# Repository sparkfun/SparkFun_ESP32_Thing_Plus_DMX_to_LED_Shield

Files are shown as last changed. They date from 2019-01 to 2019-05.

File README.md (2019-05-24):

SparkFun ESP32 Thing Plus DMX to LED Shield
========================================

SparkFun ESP32 DMX to LED Shield

[*SparkFun ESP32 DMX to LED Shield(DEV-15110)*](https://www.sparkfun.com/products/15110)

The SparkFun ESP32 DMX to LED Shield is capable of DMX output, input, as well as Artnet input. The shield is electrically isolated to keep with DMX spec. This library has been written to control DMX output and input.

Repository Contents
-------------------

* **/Hardware** - Eagle design files (.brd, .sch)
* **/Production** - Production panel files (.brd)

Documentation
--------------
* **[Hookup Guide](https://learn.sparkfun.com/tutorials/sparkfun-esp32-dmx-to-led-shield)** - Basic hookup guide for the [SparkFun ESP32 DMX to LED Shield](https://www.sparkfun.com/products/15110).

License Information
-------------------

This product is _**open source**_! 

Please review the LICENSE.md file for license information.

If you have any questions or concerns on licensing, please visit the [SparkFun Forum](https://forum.sparkfun.com/index.php) and post a topic.

Distributed as-is; no warranty is given.

- Your friends at SparkFun.

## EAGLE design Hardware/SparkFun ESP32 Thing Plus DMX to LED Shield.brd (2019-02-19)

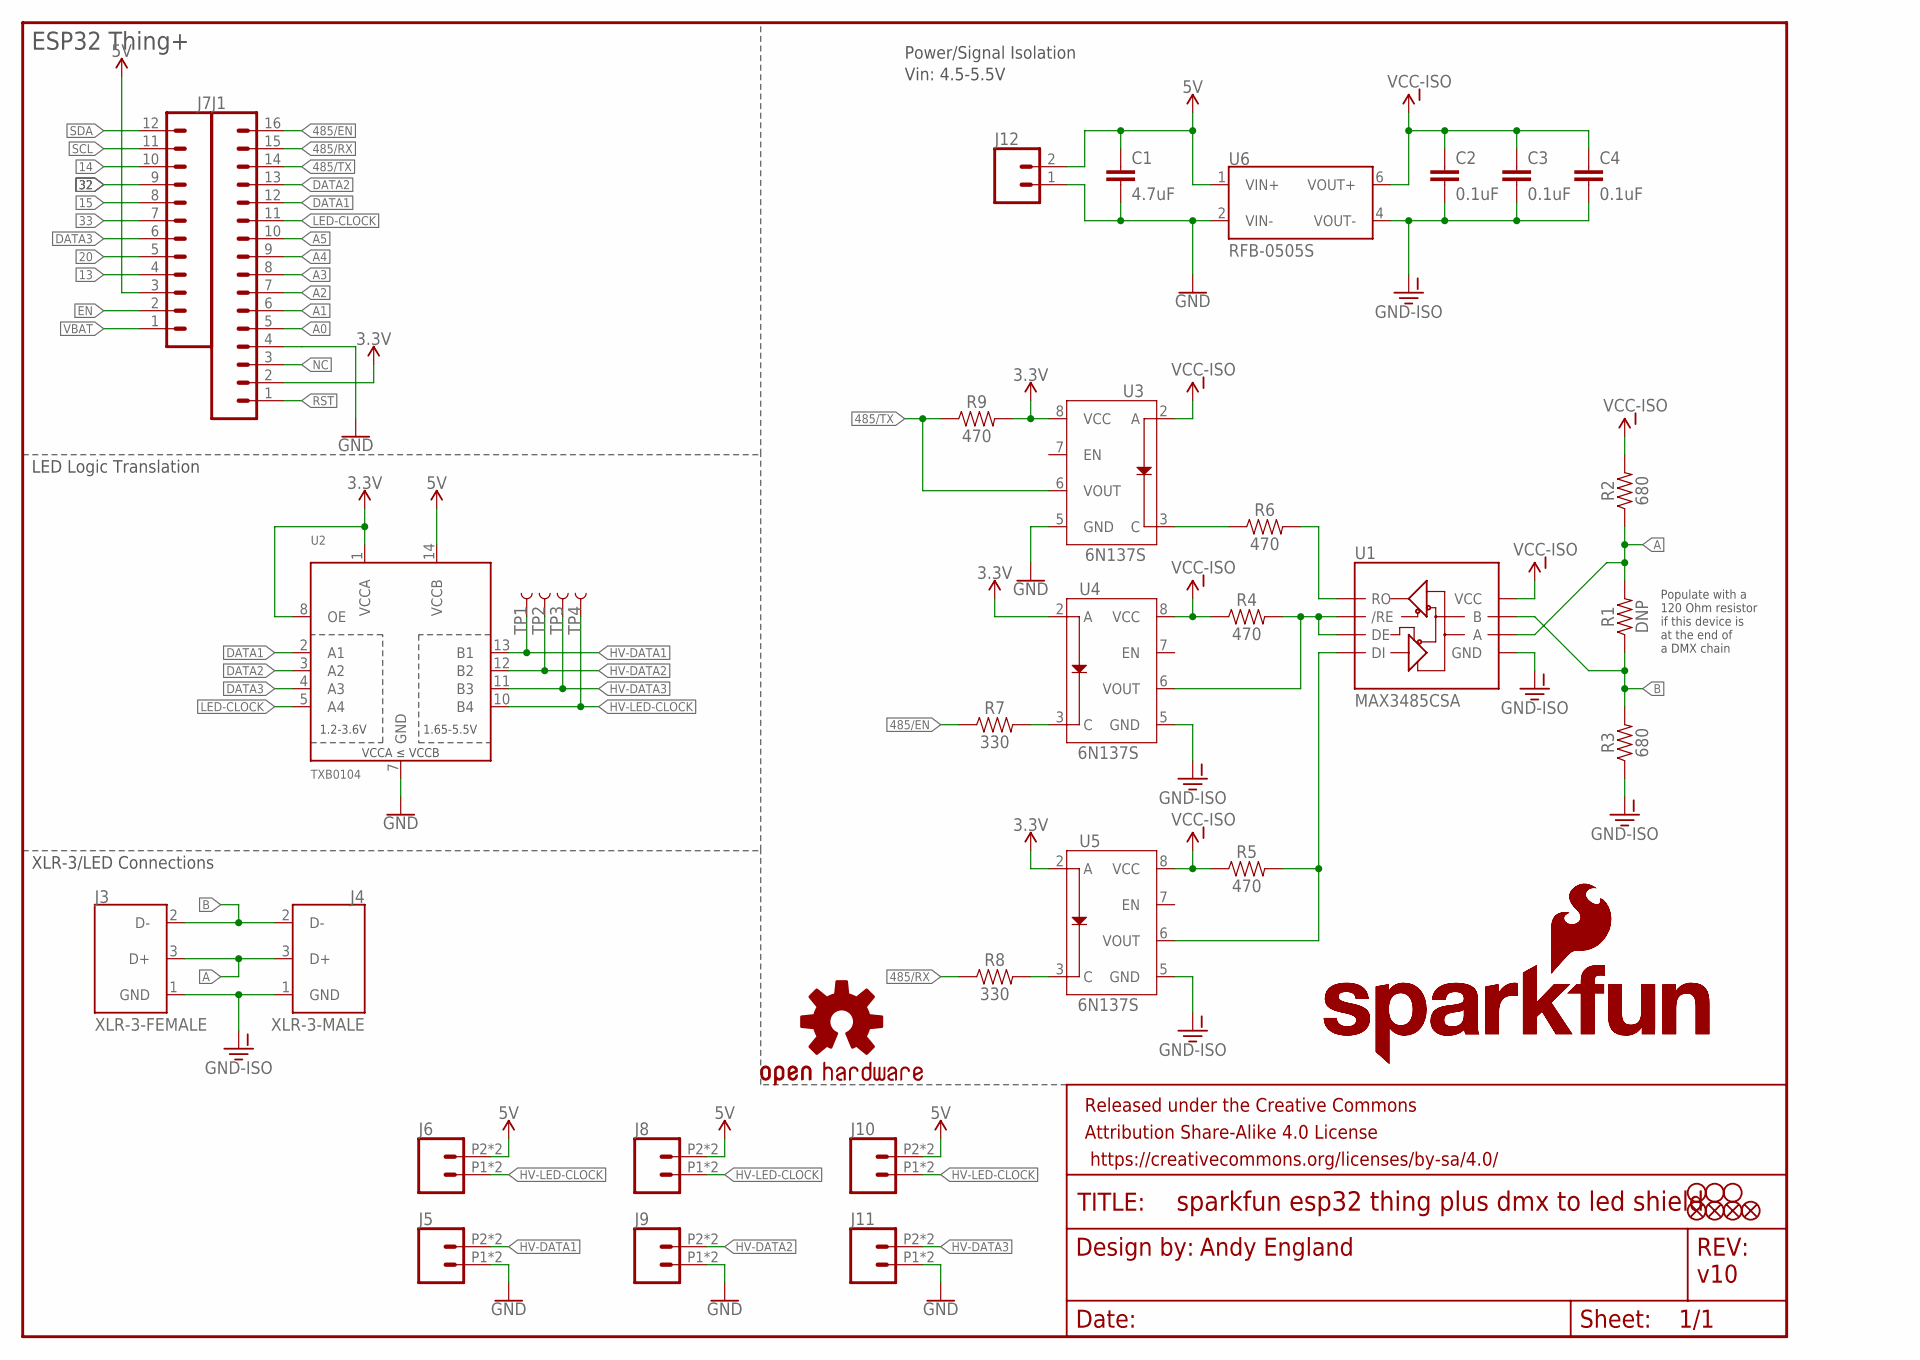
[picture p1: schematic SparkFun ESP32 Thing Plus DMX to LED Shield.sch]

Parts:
C1: 4.7uF; 0603
C2, C3, C4: 0.1uF; 0603
FD1, FD2, FD3, FD4: FIDUCIALUFIDUCIAL; FIDUCIAL-MICRO
FRAME1: FRAME-LETTER; CREATIVE_COMMONS
H1, H2, H3: STAND-OFFTIGHT; STAND-OFF-TIGHT
J1: CONN_16LOCK_NO_SILK; 1X16_LOCK_NO_SILK
J3: XLR-3-FEMALE; XLR-3_FEMALE
J4: XLR-3-MALE; XLR-3_MALE
J5, J6, J8, J9, J10, J11: CONN_02SMALL_POKEHOME; 1X02_POKEHOME
J7: CONN_12LOCK_NO_SILK; 1X12_LOCK_NO_SILK
J12: CONN_023.5MM; SCREWTERMINAL-3.5MM-2
LOGO1, LOGO2: SFE_LOGO_NAME_FLAME.2_INCH; SFE_LOGO_NAME_FLAME_.2
LOGO3: OSHW-LOGOS; OSHW-LOGO-S
R1: DNP; AXIAL-0.3EZ
R2, R3: 680; 0603
R4, R5, R6, R9: 470; 0603
R7, R8: 330; 0603
TP1, TP2, TP3, TP4: TEST-POINT3; PAD.03X.03
U1: MAX3485CSA; SO08
U2: TXB0104; TSSOP14
U3, U4, U5: 6N137S; 8-SMD
U6: RFB-0505S

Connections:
3.3V: J1.2, R9.2, U2.1 (VCCA), U2.8 (OE), U3.8 (VCC), U4.2 (A), U5.2 (A)
5V: C1.1, J6.P2 (2), J6.P4 (2), J7.3, J8.P2 (2), J8.P4 (2), J10.P2 (2), J10.P4 (2), J12.2, U2.14 (VCCB), U6.1 (VIN+)
13: J7.4
14: J7.10
15: J7.8
20: J7.5
32: J7.9
33: J7.7
485/EN: J1.16, R7.1
485/RX: J1.15, R8.1
485/TX: J1.14, R9.1, U3.6 (VOUT)
A: J3.3 (D+), J4.3 (D+), R1.P$2 (2), R2.1, U1.6 (A)
A0: J1.5
A1: J1.6
A2: J1.7
A3: J1.8
A4: J1.9
A5: J1.10
B: J3.2 (D-), J4.2 (D-), R1.P$1 (1), R3.2, U1.7 (B)
DATA1: J1.12, U2.2 (A1)
DATA2: J1.13, U2.3 (A2)
DATA3: J7.6, U2.4 (A3)
EN: J7.2
GND: C1.2, J1.4, J5.P1 (1), J5.P3 (1), J9.P1 (1), J9.P3 (1), J11.P1 (1), J11.P3 (1), J12.1, U2.7 (GND), U3.5 (GND), U6.2 (VIN-)
GND-ISO: C2.2, C3.2, C4.2, J3.1 (GND), J4.1 (GND), R3.1, U1.5 (GND), U4.5 (GND), U5.5 (GND), U6.4 (VOUT-)
HV-DATA1: J5.P2 (2), J5.P4 (2), TP1.P$1, U2.13 (B1)
HV-DATA2: J9.P2 (2), J9.P4 (2), TP2.P$1, U2.12 (B2)
HV-DATA3: J11.P2 (2), J11.P4 (2), TP3.P$1, U2.11 (B3)
HV-LED-CLOCK: J6.P1 (1), J6.P3 (1), J8.P1 (1), J8.P3 (1), J10.P1 (1), J10.P3 (1), TP4.P$1, U2.10 (B4)
LED-CLOCK: J1.11, U2.5 (A4)
unnamed: R8.2, U5.3 (C)
unnamed: R7.2, U4.3 (C)
unnamed: R4.2, U1.2 (/RE), U1.3 (DE), U4.6 (VOUT)
unnamed: R5.2, U1.4 (DI), U5.6 (VOUT)
unnamed: R6.1, U3.3 (C)
unnamed: R6.2, U1.1 (RO)
NC: J1.3
RST: J1.1
SCL: J7.11
SDA: J7.12
VBAT: J7.1
VCC-ISO: C2.1, C3.1, C4.1, R2.2, R4.1, R5.1, U1.8 (VCC), U3.2 (A), U4.8 (VCC), U5.8 (VCC), U6.6 (VOUT+)

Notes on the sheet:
ESP32 Thing+
Andy England
v10
LED Logic Translation
Power/Signal Isolation
XLR-3/LED Connections
Populate with a 120 Ohm resistor if this device is at the end of a DMX chain
Vin: 4.5-5.5V

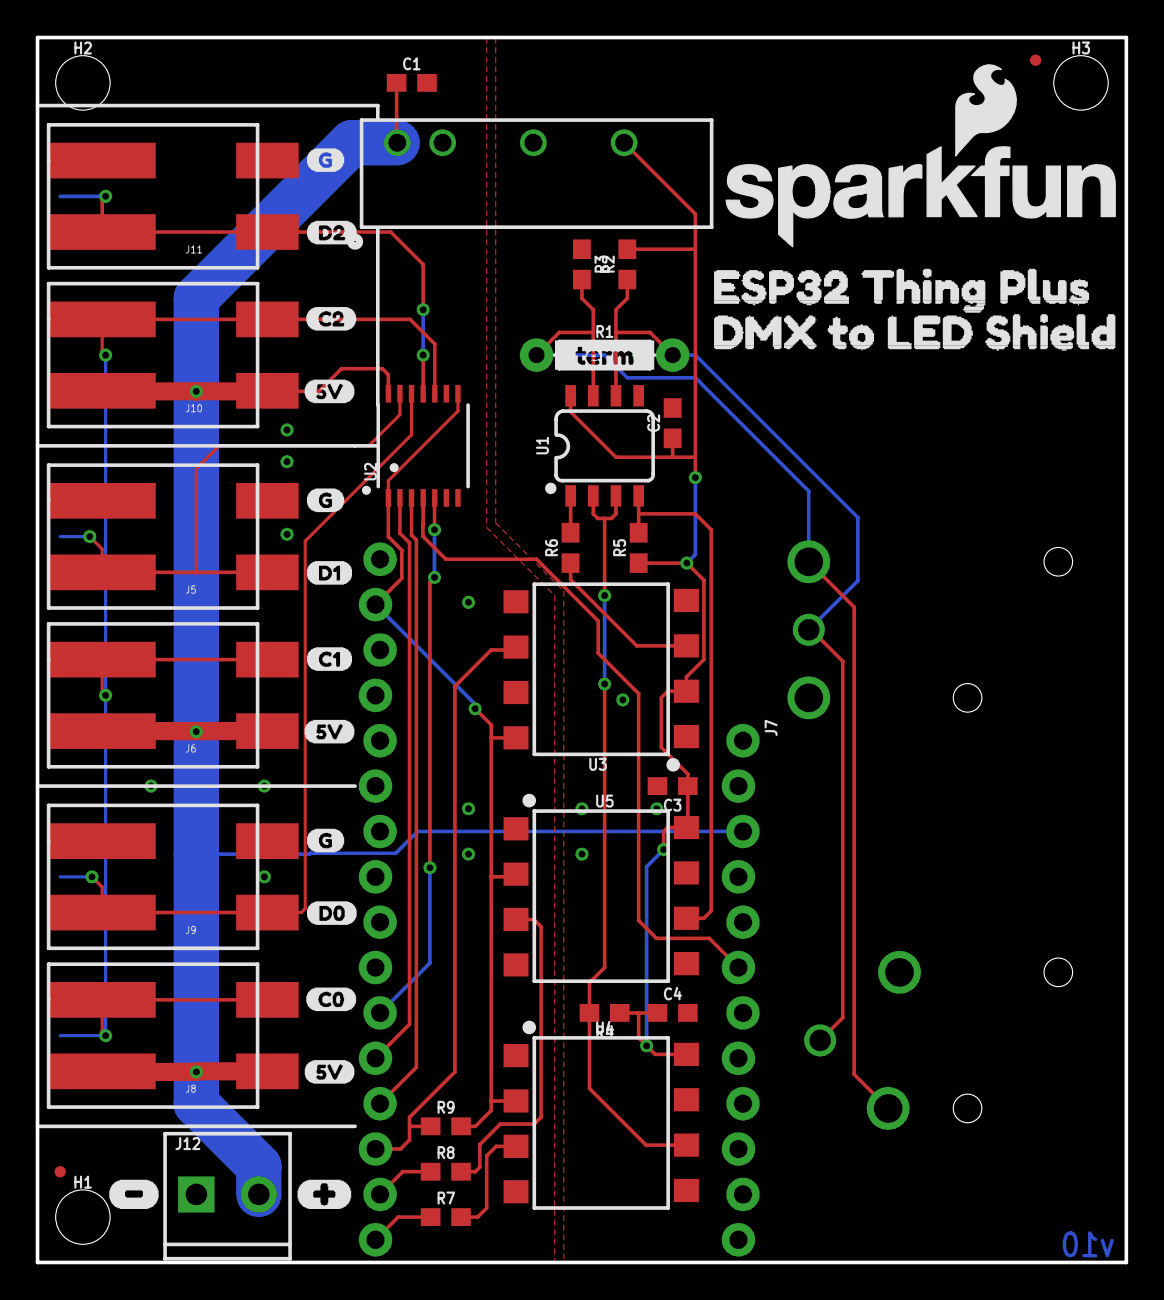
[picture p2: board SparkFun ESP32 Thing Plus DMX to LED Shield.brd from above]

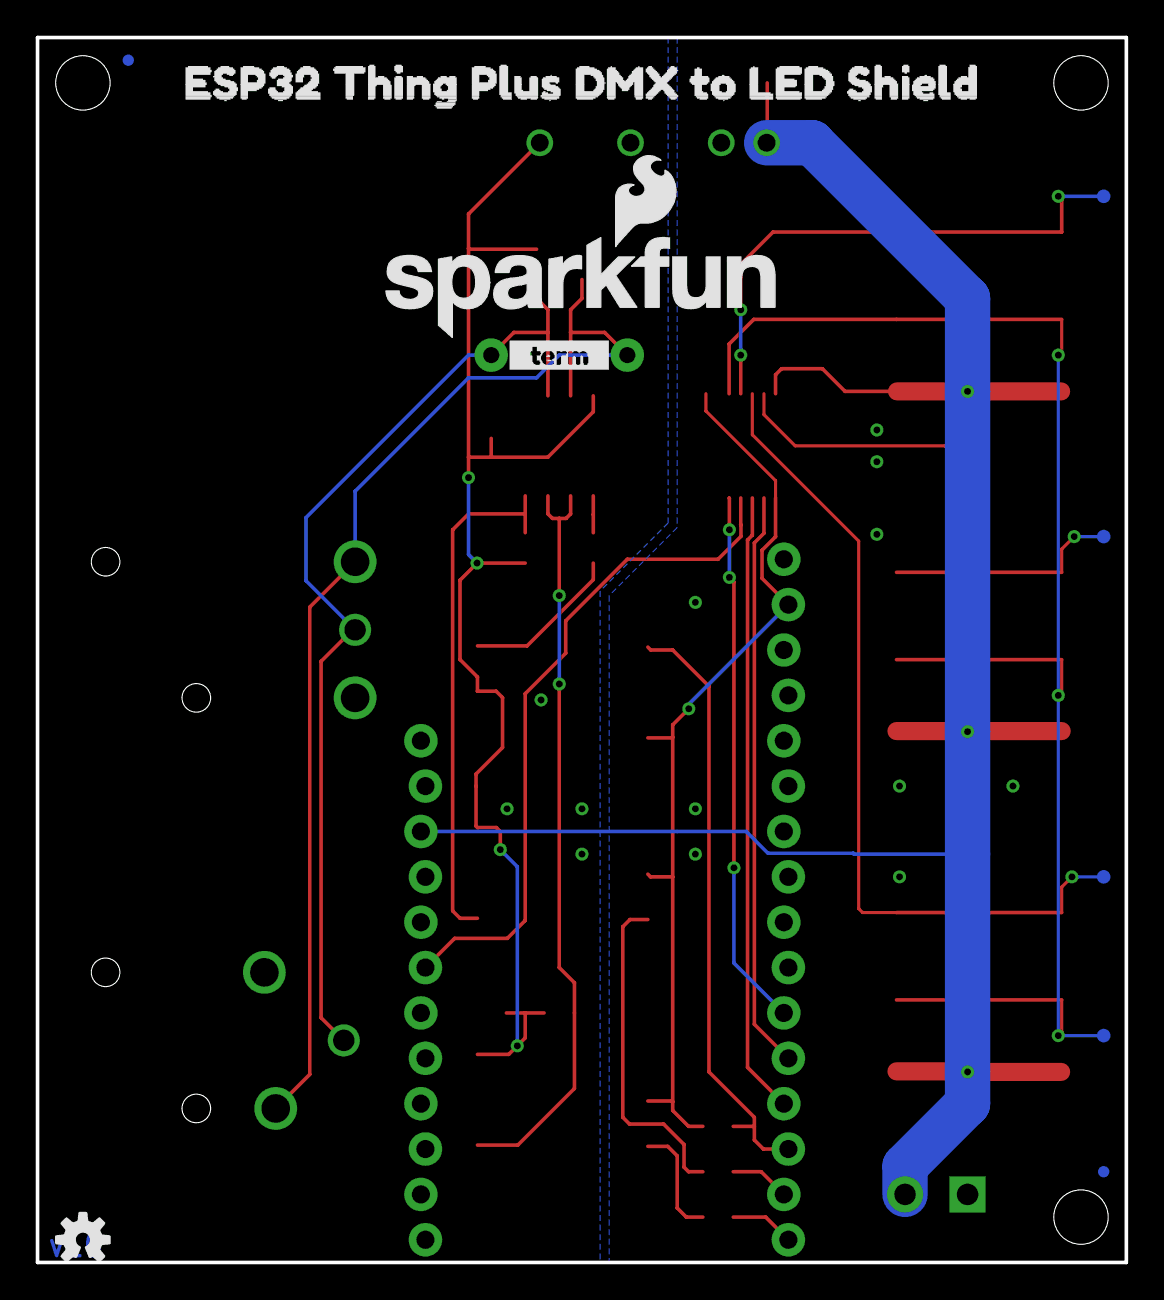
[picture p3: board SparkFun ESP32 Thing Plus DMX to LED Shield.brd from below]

Board: 2 copper layers, 61.0 x 68.6 mm, 65 parts (11 on the bottom side), 24 nets.

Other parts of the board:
U$1, U$2: __TERM__0
U$11, U$13: ESP32_THING_PLUS6
U$12, U$14: DMX_TO_LED_SHIELD7
U$15, U$17, U$21: 5V7
U$16: #0
U$18: C01
U$19: D00
U$20, U$24, U$28: G8
U$22: C12
U$23: D16
U$25: #1
U$26: C24
U$27: D23

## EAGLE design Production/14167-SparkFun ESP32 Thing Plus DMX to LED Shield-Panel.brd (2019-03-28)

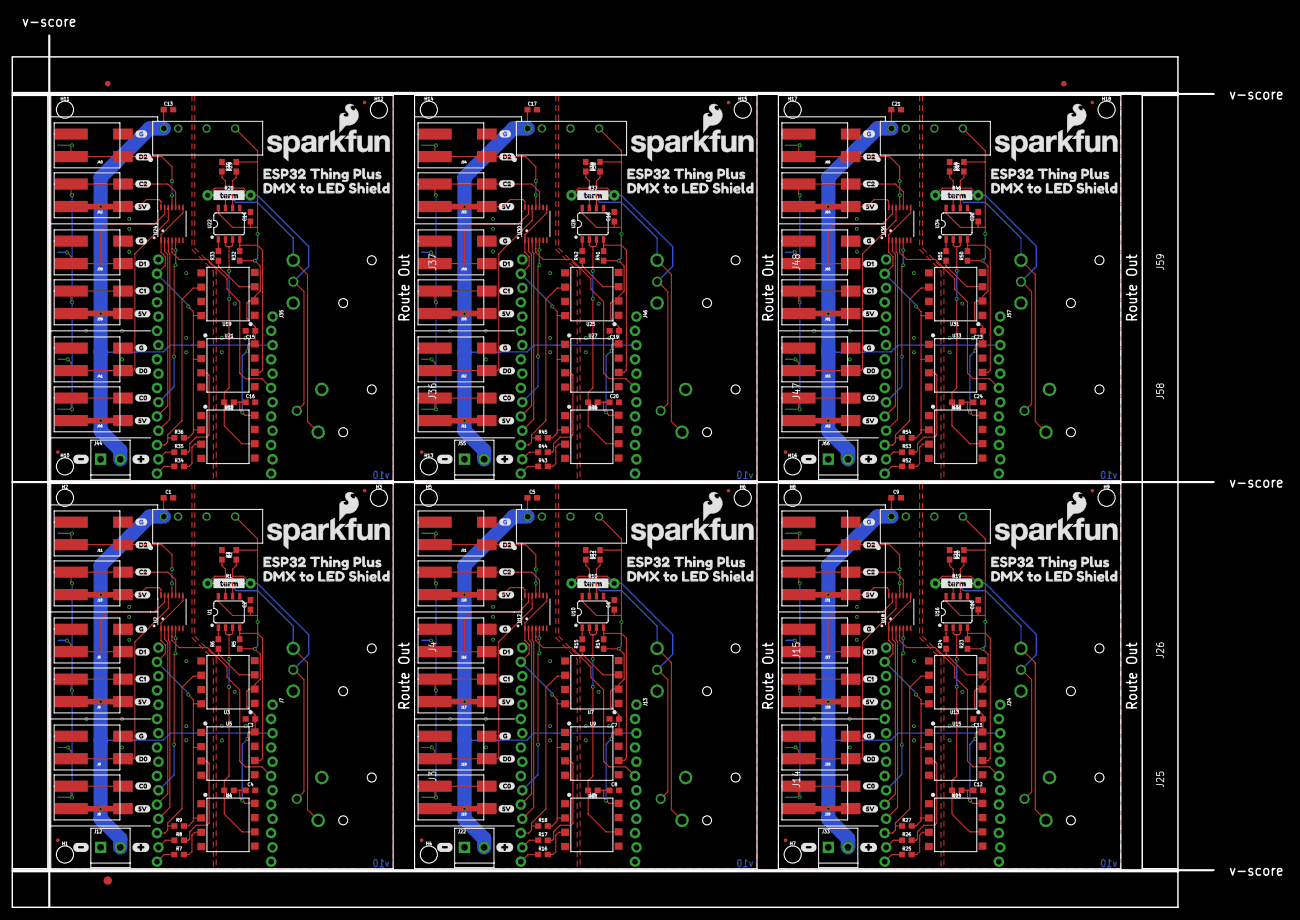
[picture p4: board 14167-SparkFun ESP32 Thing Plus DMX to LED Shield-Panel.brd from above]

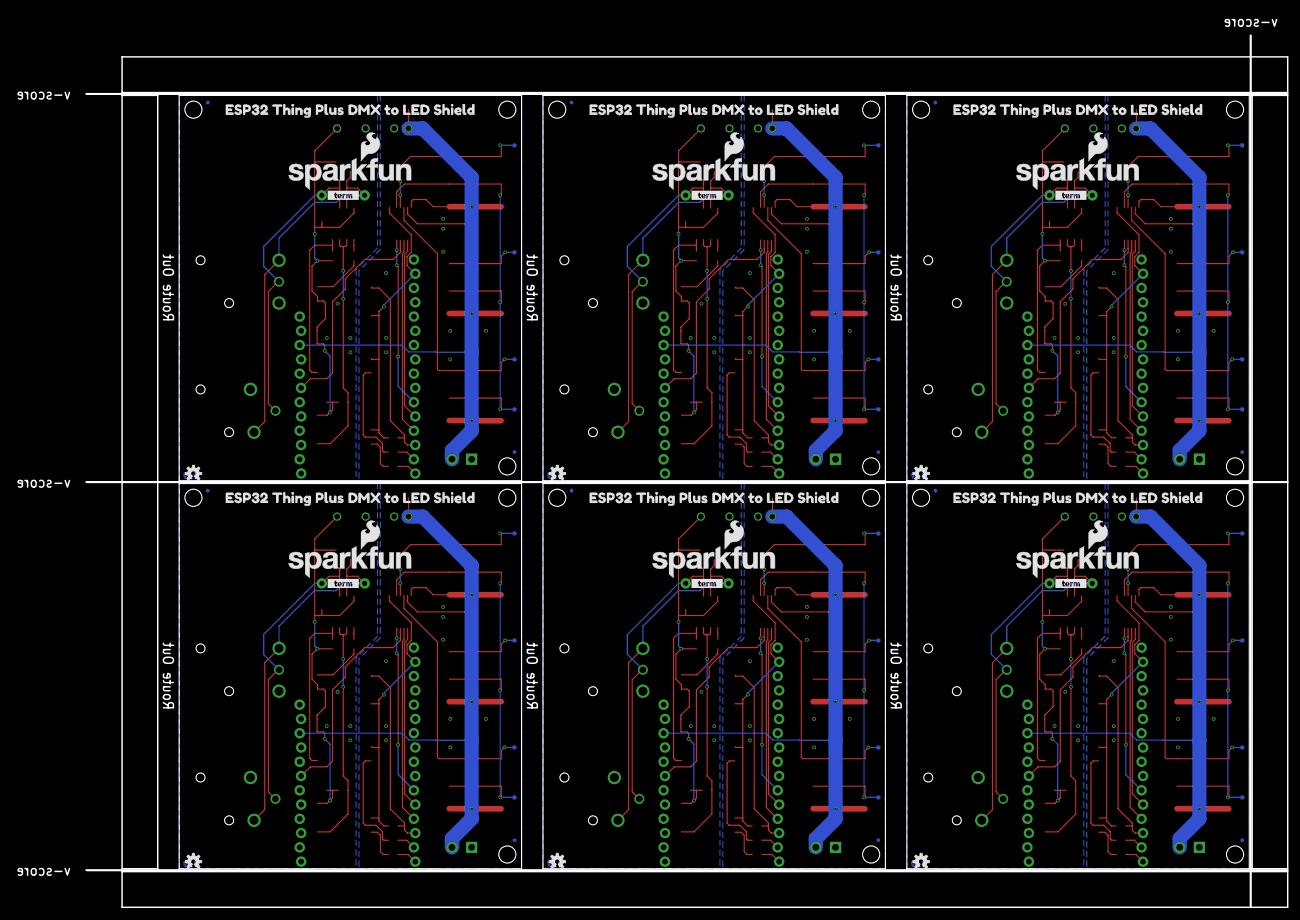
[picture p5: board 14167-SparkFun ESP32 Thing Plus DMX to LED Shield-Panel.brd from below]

Board: 2 copper layers, 213.8 x 155.2 mm, 387 parts (66 on the bottom side), 144 nets.

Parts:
C1, C5, C9, C13, C17, C21: 4.7uF; 0603
C2, C3, C4, C6, C7, C8, C10, C11, C12, C14, C15, C16, C18, C19, C20, C22, C23, C24: 0.1uF; 0603
E$1, E$2: FIDUCIAL-1X2
E$3: FIDUCIAL-1.5X3
FD1, FD2, FD3, FD4, FD5, FD6, FD7, FD8, FD9, FD10, FD11, FD12, FD13, FD14, FD15, FD16, FD17, FD18, FD19, FD20, FD21, FD22, FD23, FD24: FIDUCIALUFIDUCIAL; FIDUCIAL-MICRO
H1, H2, H3, H4, H5, H6, H7, H8, H9, H10, H11, H12, H13, H14, H15, H16, H17, H18: STAND-OFFTIGHT; STAND-OFF-TIGHT
J1, J2, J23, J34, J45, J56: 1X16_LOCK_NO_SILK
J3, J14, J25, J36, J47, J58: XLR-3-FEMALE; XLR-3_FEMALE
J4, J15, J26, J37, J48, J59: XLR-3-MALE; XLR-3_MALE
J5, J6, J8, J9, J10, J11, J16, J17, J18, J19, J20, J21, J27, J28, J29, J30, J31, J32, J38, J39, J40, J41, J42, J43, J49, J50, J51, J52, J53, J54, J60, J61, J62, J63, J64, J65: 1X02_POKEHOME
J7, J13, J24, J35, J46, J57: 1X12_LOCK_NO_SILK
J12, J22, J33, J44, J55, J66: SCREWTERMINAL-3.5MM-2
LOGO1, LOGO2, LOGO4, LOGO5, LOGO7, LOGO8, LOGO10, LOGO11, LOGO13, LOGO14, LOGO16, LOGO17: SFE_LOGO_NAME_FLAME.2_INCH; SFE_LOGO_NAME_FLAME_.2
LOGO3, LOGO6, LOGO9, LOGO12, LOGO15, LOGO18: OSHW-LOGOS; OSHW-LOGO-S
R1, R10, R19, R28, R37, R46: DNP; AXIAL-0.3EZ
R2, R3, R11, R12, R20, R21, R29, R30, R38, R39, R47, R48: 680; 0603
R4, R5, R6, R9, R13, R14, R15, R18, R22, R23, R24, R27, R31, R32, R33, R36, R40, R41, R42, R45, R49, R50, R51, R54: 470; 0603
R7, R8, R16, R17, R25, R26, R34, R35, R43, R44, R52, R53: 330; 0603
TP1, TP2, TP3, TP4, TP5, TP6, TP7, TP8, TP9, TP10, TP11, TP12, TP13, TP14, TP15, TP16, TP17, TP18, TP19, TP20, TP21, TP22, TP23, TP24: TEST-POINT3; PAD.03X.03
U1, U10, U16, U22, U28, U34: MAX3485CSA; SO08
U2, U12, U18, U24, U30, U36: TXB0104; TSSOP14
U3, U4, U5, U7, U8, U9, U13, U14, U15, U19, U20, U21, U25, U26, U27, U31, U32, U33: 6N137S; 8-SMD
U6, U11, U17, U23, U29, U35: RFB-0505S
U$1, U$2, U$39, U$40, U$59, U$60, U$79, U$80, U$99, U$100, U$119, U$120: __TERM__0
U$3, U$5, U$11, U$13, U$41, U$43, U$61, U$63, U$81, U$83, U$101, U$103: ESP32_THING_PLUS6
U$4, U$6, U$12, U$14, U$42, U$44, U$62, U$64, U$82, U$84, U$102, U$104: DMX_TO_LED_SHIELD7
U$7, U$8, U$15, U$17, U$21, U$30, U$45, U$46, U$50, U$65, U$66, U$70, U$85, U$86, U$90, U$105, U$106, U$110: 5V7
U$9, U$18, U$47, U$67, U$87, U$107: C01
U$10, U$19, U$48, U$68, U$88, U$108: D00
U$16, U$37, U$57, U$77, U$97, U$117: #0
U$20, U$24, U$28, U$29, U$33, U$36, U$49, U$53, U$56, U$69, U$73, U$76, U$89, U$93, U$96, U$109, U$113, U$116: G8
U$22, U$31, U$51, U$71, U$91, U$111: C12
U$23, U$32, U$52, U$72, U$92, U$112: D16
U$25, U$38, U$58, U$78, U$98, U$118: #1
U$26, U$34, U$54, U$74, U$94, U$114: C24
U$27, U$35, U$55, U$75, U$95, U$115: D23

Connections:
3.3V: J1.2, R9.2, U2.1, U2.8, U3.8, U4.2, U5.2
3.3V1: J2.2, R18.2, U7.8, U8.2, U9.2, U12.1, U12.8
3.3V2: J23.2, R27.2, U13.8, U14.2, U15.2, U18.1, U18.8
3.3V3: J34.2, R36.2, U19.8, U20.2, U21.2, U24.1, U24.8
3.3V4: J45.2, R45.2, U25.8, U26.2, U27.2, U30.1, U30.8
3.3V5: J56.2, R54.2, U31.8, U32.2, U33.2, U36.1, U36.8
5V: C1.1, J6.P2, J6.P4, J7.3, J8.P2, J8.P4, J10.P2, J10.P4, J12.2, U2.14, U6.1
5V1: C5.1, J13.3, J17.P2, J17.P4, J18.P2, J18.P4, J20.P2, J20.P4, J22.2, U11.1, U12.14
5V2: C9.1, J24.3, J28.P2, J28.P4, J29.P2, J29.P4, J31.P2, J31.P4, J33.2, U17.1, U18.14
5V3: C13.1, J35.3, J39.P2, J39.P4, J40.P2, J40.P4, J42.P2, J42.P4, J44.2, U23.1, U24.14
5V4: C17.1, J46.3, J50.P2, J50.P4, J51.P2, J51.P4, J53.P2, J53.P4, J55.2, U29.1, U30.14
5V5: C21.1, J57.3, J61.P2, J61.P4, J62.P2, J62.P4, J64.P2, J64.P4, J66.2, U35.1, U36.14
485/EN: J1.16, R7.1
485/EN1: J2.16, R16.1
485/EN2: J23.16, R25.1
485/EN3: J34.16, R34.1
485/EN4: J45.16, R43.1
485/EN5: J56.16, R52.1
485/RX: J1.15, R8.1
485/RX1: J2.15, R17.1
485/RX2: J23.15, R26.1
485/RX3: J34.15, R35.1
485/RX4: J45.15, R44.1
485/RX5: J56.15, R53.1
485/TX: J1.14, R9.1, U3.6
485/TX1: J2.14, R18.1, U7.6
485/TX2: J23.14, R27.1, U13.6
485/TX3: J34.14, R36.1, U19.6
485/TX4: J45.14, R45.1, U25.6
485/TX5: J56.14, R54.1, U31.6
A: J3.3, J4.3, R1.P$2, R2.1, U1.6
A12: J14.3, J15.3, R10.P$2, R11.1, U10.6
A19: J25.3, J26.3, R19.P$2, R20.1, U16.6
A26: J36.3, J37.3, R28.P$2, R29.1, U22.6
A33: J47.3, J48.3, R37.P$2, R38.1, U28.6
A40: J58.3, J59.3, R46.P$2, R47.1, U34.6
B: J3.2, J4.2, R1.P$1, R3.2, U1.7
B1: J14.2, J15.2, R10.P$1, R12.2, U10.7
B2: J25.2, J26.2, R19.P$1, R21.2, U16.7
B3: J36.2, J37.2, R28.P$1, R30.2, U22.7
B4: J47.2, J48.2, R37.P$1, R39.2, U28.7
B5: J58.2, J59.2, R46.P$1, R48.2, U34.7
DATA1: J1.12, U2.2
DATA2: J1.13, U2.3
DATA3: J7.6, U2.4
DATA4: J13.6, U12.4
DATA5: J2.13, U12.3
DATA6: J2.12, U12.2
DATA7: J24.6, U18.4
DATA8: J23.13, U18.3
DATA9: J23.12, U18.2
DATA10: J35.6, U24.4
DATA11: J34.13, U24.3
DATA12: J34.12, U24.2
DATA13: J46.6, U30.4
DATA14: J45.13, U30.3
DATA15: J45.12, U30.2
DATA16: J57.6, U36.4
DATA17: J56.13, U36.3
DATA18: J56.12, U36.2
GND: C1.2, J1.4, J5.P1, J5.P3, J9.P1, J9.P3, J11.P1, J11.P3, J12.1, U2.7, U3.5, U6.2
GND1: C5.2, J2.4, J16.P1, J16.P3, J19.P1, J19.P3, J21.P1, J21.P3, J22.1, U7.5, U11.2, U12.7
GND2: C9.2, J23.4, J27.P1, J27.P3, J30.P1, J30.P3, J32.P1, J32.P3, J33.1, U13.5, U17.2, U18.7
GND3: C13.2, J34.4, J38.P1, J38.P3, J41.P1, J41.P3, J43.P1, J43.P3, J44.1, U19.5, U23.2, U24.7
GND4: C17.2, J45.4, J49.P1, J49.P3, J52.P1, J52.P3, J54.P1, J54.P3, J55.1, U25.5, U29.2, U30.7
GND5: C21.2, J56.4, J60.P1, J60.P3, J63.P1, J63.P3, J65.P1, J65.P3, J66.1, U31.5, U35.2, U36.7
GND-ISO: C2.2, C3.2, C4.2, J3.1, J4.1, R3.1, U1.5, U4.5, U5.5, U6.4
GND-ISO1: C6.2, C7.2, C8.2, J14.1, J15.1, R12.1, U8.5, U9.5, U10.5, U11.4
GND-ISO2: C10.2, C11.2, C12.2, J25.1, J26.1, R21.1, U14.5, U15.5, U16.5, U17.4
GND-ISO3: C14.2, C15.2, C16.2, J36.1, J37.1, R30.1, U20.5, U21.5, U22.5, U23.4
GND-ISO4: C18.2, C19.2, C20.2, J47.1, J48.1, R39.1, U26.5, U27.5, U28.5, U29.4
GND-ISO5: C22.2, C23.2, C24.2, J58.1, J59.1, R48.1, U32.5, U33.5, U34.5, U35.4
HV-DATA1: J5.P2, J5.P4, TP1.P$1, U2.13
HV-DATA2: J9.P2, J9.P4, TP2.P$1, U2.12
HV-DATA3: J11.P2, J11.P4, TP3.P$1, U2.11
HV-DATA4: J19.P2, J19.P4, TP6.P$1, U12.12
HV-DATA5: J21.P2, J21.P4, TP7.P$1, U12.11
HV-DATA6: J16.P2, J16.P4, TP5.P$1, U12.13
HV-DATA7: J30.P2, J30.P4, TP10.P$1, U18.12
HV-DATA8: J32.P2, J32.P4, TP11.P$1, U18.11
HV-DATA9: J27.P2, J27.P4, TP9.P$1, U18.13
HV-DATA10: J41.P2, J41.P4, TP14.P$1, U24.12
HV-DATA11: J43.P2, J43.P4, TP15.P$1, U24.11
HV-DATA12: J38.P2, J38.P4, TP13.P$1, U24.13
HV-DATA13: J52.P2, J52.P4, TP18.P$1, U30.12
HV-DATA14: J54.P2, J54.P4, TP19.P$1, U30.11
HV-DATA15: J49.P2, J49.P4, TP17.P$1, U30.13
HV-DATA16: J63.P2, J63.P4, TP22.P$1, U36.12
HV-DATA17: J65.P2, J65.P4, TP23.P$1, U36.11
HV-DATA18: J60.P2, J60.P4, TP21.P$1, U36.13
HV-LED-CLOCK: J6.P1, J6.P3, J8.P1, J8.P3, J10.P1, J10.P3, TP4.P$1, U2.10
HV-LED-CLOCK1: J17.P1, J17.P3, J18.P1, J18.P3, J20.P1, J20.P3, TP8.P$1, U12.10
HV-LED-CLOCK2: J28.P1, J28.P3, J29.P1, J29.P3, J31.P1, J31.P3, TP12.P$1, U18.10
HV-LED-CLOCK3: J39.P1, J39.P3, J40.P1, J40.P3, J42.P1, J42.P3, TP16.P$1, U24.10
HV-LED-CLOCK4: J50.P1, J50.P3, J51.P1, J51.P3, J53.P1, J53.P3, TP20.P$1, U30.10
HV-LED-CLOCK5: J61.P1, J61.P3, J62.P1, J62.P3, J64.P1, J64.P3, TP24.P$1, U36.10
LED-CLOCK: J1.11, U2.5
LED-CLOCK1: J2.11, U12.5
LED-CLOCK2: J23.11, U18.5
LED-CLOCK3: J34.11, U24.5
LED-CLOCK4: J45.11, U30.5
LED-CLOCK5: J56.11, U36.5
unnamed: R8.2, U5.3
unnamed: R7.2, U4.3
unnamed: R4.2, U1.2, U1.3, U4.6
unnamed: R5.2, U1.4, U5.6
unnamed: R6.1, U3.3
unnamed: R6.2, U1.1
unnamed: R13.2, U8.6, U10.2, U10.3
unnamed: R15.1, U7.3
unnamed: R15.2, U10.1
unnamed: R14.2, U9.6, U10.4
unnamed: R17.2, U9.3
unnamed: R16.2, U8.3
unnamed: R22.2, U14.6, U16.2, U16.3
unnamed: R24.1, U13.3
unnamed: R24.2, U16.1
unnamed: R23.2, U15.6, U16.4
unnamed: R26.2, U15.3
unnamed: R25.2, U14.3
unnamed: R31.2, U20.6, U22.2, U22.3
unnamed: R33.1, U19.3
unnamed: R33.2, U22.1
unnamed: R32.2, U21.6, U22.4
unnamed: R35.2, U21.3
unnamed: R34.2, U20.3
unnamed: R40.2, U26.6, U28.2, U28.3
unnamed: R42.1, U25.3
unnamed: R42.2, U28.1
unnamed: R41.2, U27.6, U28.4
unnamed: R44.2, U27.3
unnamed: R43.2, U26.3
unnamed: R49.2, U32.6, U34.2, U34.3
unnamed: R51.1, U31.3
unnamed: R51.2, U34.1
unnamed: R50.2, U33.6, U34.4
unnamed: R53.2, U33.3
unnamed: R52.2, U32.3
VCC-ISO: C2.1, C3.1, C4.1, R2.2, R4.1, R5.1, U1.8, U3.2, U4.8, U5.8, U6.6
VCC-ISO1: C6.1, C7.1, C8.1, R11.2, R13.1, R14.1, U7.2, U8.8, U9.8, U10.8, U11.6
VCC-ISO2: C10.1, C11.1, C12.1, R20.2, R22.1, R23.1, U13.2, U14.8, U15.8, U16.8, U17.6
VCC-ISO3: C14.1, C15.1, C16.1, R29.2, R31.1, R32.1, U19.2, U20.8, U21.8, U22.8, U23.6
VCC-ISO4: C18.1, C19.1, C20.1, R38.2, R40.1, R41.1, U25.2, U26.8, U27.8, U28.8, U29.6
VCC-ISO5: C22.1, C23.1, C24.1, R47.2, R49.1, R50.1, U31.2, U32.8, U33.8, U34.8, U35.6

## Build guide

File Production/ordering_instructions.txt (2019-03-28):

panel size, 211x152mm
PCB thickness, 1.6mm
number of layers, 2
soldermask color, Red
silkscreen color, White
oz copper, 1oz
finish, HASL lead free
stencils, none
pcs per panel, 6

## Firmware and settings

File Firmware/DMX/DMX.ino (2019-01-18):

#include <WiFi.h>
#include <WiFiUdp.h>
#include <ArtnetWifi.h>
#include <FastLED.h>
#include <LXESP32DMX.h> //https://github.com/claudeheintz/LXESP32DMX

//Wifi settings
char ssid[] = "myDMX";
char password[] = "artnetnode";
IPAddress local_IP(192, 168, 1, 184);
IPAddress gateway(192, 168, 1, 1);
IPAddress subnet(255, 255, 255, 0);

// Artnet settings
ArtnetWifi artnet;
const int startUniverse = 0;
const int endUniverse = 1;

bool sendFrame = 1;
int previousDataLength = 0;

//Pin Definitions for Shield
#define RX 16
#define TX 17
#define EN 21
#define LED_DATA1 27
#define LED_DATA2 18
#define LED_DATA3 19
#define LED_CLOCK 5

//LED String Definitions
#define NUM_LEDS1 0
#define NUM_LEDS2 192
#define NUM_LEDS3 0
#define TOTAL_LEDS NUM_LEDS1 + NUM_LEDS2 + NUM_LEDS3
CRGB ledString1[NUM_LEDS1];
CRGB ledString2[NUM_LEDS2];
CRGB ledString3[NUM_LEDS3];

uint8_t hue = 0;

boolean connectWifi(void)
{
  boolean state = true;
  WiFi.mode(WIFI_AP_STA);
  state = WiFi.softAP(ssid, password);
  return state;
}

void beginXLROut()
{
  pinMode(EN, OUTPUT);
  digitalWrite(EN, HIGH);

  pinMode(TX, OUTPUT);
  ESP32DMX.startOutput(TX);
}

//Beginning XLR Input will mean that the output will simply be a throughput
void beginXLRIn()
{
  pinMode(EN, OUTPUT);
  digitalWrite(EN, LOW);

  pinMode(RX, INPUT);
  ESP32DMX.startInput(RX);
}

void onDmxFrame(uint16_t universe, uint16_t length, uint8_t sequence, uint8_t* data)
{
  sendFrame = 1;
  // set brightness of the whole strip
  if (universe == 15)
  {
    FastLED.setBrightness(data[0]);
  }
  // read universe and put into the right part of the display buffer
  for (int i = 0; i < length / 3; i++)
  {
    int led = i + (universe - startUniverse) * (previousDataLength / 3);
    if (led < NUM_LEDS1)
    {
      ledString1[led] = CRGB(data[i * 3], data[i * 3 + 1], data[i * 3 + 2]);
    }
    else if (led < NUM_LEDS2 + NUM_LEDS1 && led >= NUM_LEDS1)
    {
      ledString2[led] = CRGB(data[i * 3], data[i * 3 + 1], data[i * 3 + 2]);
    }
    else if (led < TOTAL_LEDS && led >= NUM_LEDS1 + NUM_LEDS2)
    {
      ledString3[led] = CRGB(data[i * 3], data[i * 3 + 1], data[i * 3 + 2]);
    }
  }
  previousDataLength = length;
  if (universe == endUniverse)
  {
    FastLED.show();
  }
}

void copyDMXToOutput(void) {
  xSemaphoreTake( ESP32DMX.lxDataLock, portMAX_DELAY );
  for (int i = 1; i < DMX_MAX_FRAME; i++) {
    ESP32DMX.setSlot(i , dmxbuffer[i]);
  }
  xSemaphoreGive( ESP32DMX.lxDataLock );
}

void artnetToXLR (uint16_t universe, uint16_t length, uint8_t sequence, uint8_t* data)
{
  //add in a check for universe number, have a dedicated XLR universe since our device can handle multiple universes
  uint8_t dmxBuffer[DMX_MAX_FRAME];
  sendFrame = 1;
  for (int i = 0; i < length; i++)
  {
    dmxBuffer[i] = data[i];
  }
  previousDataLength = length;
}

void writeChannel(uint16_t channel, uint8_t value)
{
    uint8_t dmxBuffer[DMX_MAX_FRAME];
    dmxBuffer[channel] = value;
}

void setup() {
  Serial.begin(115200);
  if (connectWifi())
  {
    Serial.println("Connected!");
    //Serial.println(WiFi.softAPIP());
  }

  //LED Initialization
  if (NUM_LEDS1 != 0)
  {
    FastLED.addLeds<WS2812, LED_DATA1, BGR>(ledString3, NUM_LEDS3);
  }
  if (NUM_LEDS2 != 0)
  {
    FastLED.addLeds<APA102, LED_DATA2, LED_CLOCK, BGR>(ledString2, NUM_LEDS2);
  }
  if (NUM_LEDS3 != 0)
  {
    FastLED.addLeds<APA102, LED_DATA3, LED_CLOCK, BGR>(ledString1, NUM_LEDS1);
  }
  FastLED.setBrightness(32);
  artnet.begin();
  artnet.setArtDmxCallback(onDmxFrame);
}

void loop() {
  artnet.read();
}

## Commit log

2018-11-21 post review changes
    [ESP32Shield.brd, ESP32Shield.sch]
2018-11-26 QC changes
    [ESP32Shield.brd]
2019-01-18 adding beginning of example code
    [ESP32Shield.GBL, ESP32Shield.GBO, ESP32Shield.GBS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]
2019-02-15 updating for reds
    [ESP32Shield.brd, ESP32Shield.sch]
2019-02-19 post checklist changes
    [ESP32Shield.brd]
2019-02-19 a few unsaved changes
    [ESP32Shield.brd, ESP32Shield.sch]
2019-02-19 changing name, post checklist changes
    [SparkFun ESP32 Thing Plus DMX to LED Shield.brd, SparkFun ESP32 Thing Plus DMX to LED Shield.sch]
2019-02-20 Created panel v10
    [14167-SparkFun ESP32 Thing Plus DMX to LED Shield-Panel.GBL, 14167-SparkFun ESP32 Thing Plus DMX to LED Shield-Panel.GBO, 14167-SparkFun ESP32 Thing Plus DMX t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]
2019-03-28 updating readme
    [ESP32Shield.brd, ESP32Shield.sch]

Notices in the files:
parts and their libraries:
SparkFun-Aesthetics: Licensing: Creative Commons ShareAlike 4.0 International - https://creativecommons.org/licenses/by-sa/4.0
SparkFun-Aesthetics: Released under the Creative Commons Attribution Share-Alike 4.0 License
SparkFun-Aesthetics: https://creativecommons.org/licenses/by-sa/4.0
